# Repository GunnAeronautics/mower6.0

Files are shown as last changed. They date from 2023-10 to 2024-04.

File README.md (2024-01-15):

# mower6.0
How to install build onto rasberry pi pico:

Get Vscode

Get Git

Install the extension platformio

Download the repository

Enable LongPaths:

For windows:

Open Registry Editor,

go to:

HKEY_LOCAL_MACHINE\SYSTEM\CurrentControlSet\Control\FileSystem.

Select the entry named: LongPathsEnabled. Set the value to 1

Run Git CMD as administrator

Run this command:

git config --system core.longpaths true

Restart your computer

Open repo in platformio and it should start to build.

Download zadig driver installation tool if you want to upload more easily

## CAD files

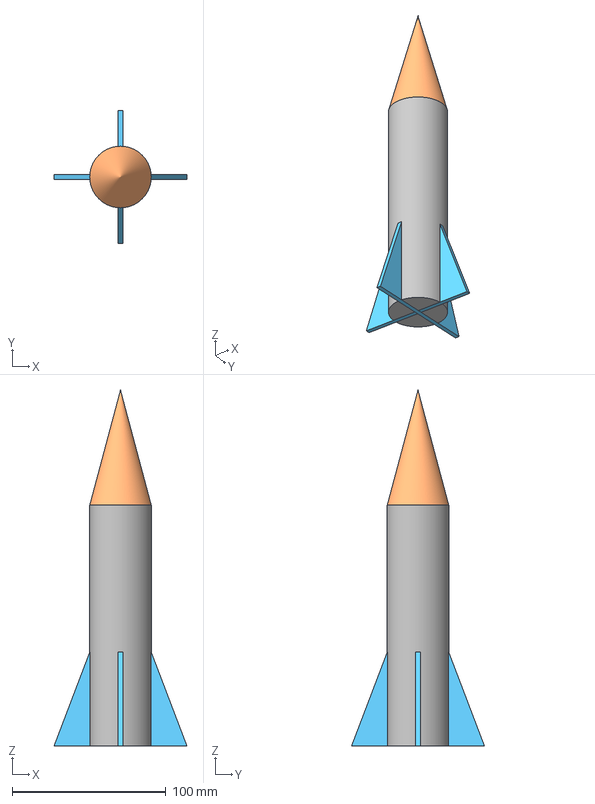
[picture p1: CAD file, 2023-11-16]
Flight Data Shenanigans/Python Testing/Rocket.3mf
86.5 x 86.5 x 231.4 mm

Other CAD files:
Flight Data Shenanigans/Python Testing/Rocket.obj

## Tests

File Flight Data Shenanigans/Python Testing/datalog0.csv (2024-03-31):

time | baro | temp | alt | altV | altA | predictApogee | srvPos | correl | state
321906 | 1007.88 | 28.06 | 0.47 | 0 | 0 | 0 | 0 | 0 | 1
321932 | 1007.9 | 28.06 | 0.48 | 0 | 0 | 0 | 0 | 0 | 1
321958 | 1007.86 | 28.05 | 0.53 | 0 | 0 | 0 | 0 | 0 | 1
321985 | 1007.89 | 28.06 | 0.51 | 0 | 0 | 0 | 0 | 0 | 1
322011 | 1007.86 | 28.06 | 0.54 | 0 | 0 | 0 | 0 | 0 | 1
322037 | 1007.89 | 28.06 | 0.51 | 0 | 0 | 0 | 0 | 0 | 1
322063 | 1007.87 | 28.06 | 0.51 | 0 | 0 | 0 | 0 | 0 | 1
322090 | 1007.87 | 28.06 | 0.47 | 0 | 0 | 0 | 0 | 0 | 1
322116 | 1007.86 | 28.06 | 0.44 | 0 | 0 | 0 | 0 | 0 | 1
322148 | 1007.87 | 28.06 | 0.42 | 0 | 0 | 0 | 0 | 0 | 1
322174 | 1007.87 | 28.05 | 0.41 | 0 | 0 | 0 | 0 | 0 | 1
322200 | 1007.89 | 28.06 | 0.36 | 0 | 0 | 0 | 0 | 0 | 1
322227 | 1007.88 | 28.06 | 0.42 | 0 | 0 | 0 | 0 | 0 | 1
322253 | 1007.9 | 28.06 | 0.42 | 0 | 0 | 0 | 0 | 0 | 1
322279 | 1007.89 | 28.06 | 0.46 | 0 | 0 | 0 | 0 | 0 | 1
322305 | 1007.88 | 28.06 | 0.42 | 0 | 0 | 0 | 0 | 0 | 1
322331 | 1007.88 | 28.06 | 0.41 | 0 | 0 | 0 | 0 | 0 | 1
322357 | 1007.9 | 28.06 | 0.4 | 0 | 0 | 0 | 0 | 0 | 1
322384 | 1007.84 | 28.06 | 0.44 | 0 | 0 | 0 | 0 | 0 | 1
322415 | 1007.89 | 28.07 | 0.42 | 0 | 0 | 0 | 0 | 0 | 1
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

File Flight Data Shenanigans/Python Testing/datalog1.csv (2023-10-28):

time | x accl | y accl | z accl | gyro x | gyro y | gyro z | pressure
6518 | 0.07 | -0.05 | 9.99 | -0.00 | 0.00 | 0.00 | 1021.80
6606 | 0.07 | -0.10 | 9.95 | -0.00 | 0.00 | 0.00 | 1021.79
6693 | 0.08 | -0.06 | 9.96 | -0.00 | 0.00 | 0.00 | 1021.79
6780 | 0.11 | -0.05 | 9.98 | -0.00 | 0.01 | 0.00 | 1021.80
6867 | 0.04 | -0.11 | 9.98 | -0.00 | 0.00 | 0.00 | 1021.78
6954 | 0.07 | -0.02 | 9.99 | -0.00 | 0.00 | 0.00 | 1021.81
7041 | 0.08 | -0.07 | 9.97 | -0.00 | 0.00 | 0.00 | 1021.80
7128 | 0.09 | -0.08 | 9.99 | -0.00 | 0.00 | 0.00 | 1021.79
7216 | 0.05 | -0.04 | 9.99 | -0.00 | 0.00 | 0.00 | 1021.78
7303 | 0.10 | -0.07 | 9.97 | -0.00 | 0.00 | 0.01 | 1021.75
7395 | 0.06 | -0.07 | 9.98 | -0.00 | 0.00 | 0.00 | 1021.81
7482 | 0.09 | -0.05 | 9.99 | -0.00 | 0.00 | 0.00 | 1021.79
7569 | 0.07 | -0.08 | 9.98 | -0.00 | 0.00 | 0.00 | 1021.76
7657 | 0.07 | -0.04 | 10.00 | -0.00 | 0.00 | 0.00 | 1021.77
7744 | -1.97 | 1.45 | 10.02 | -0.01 | 0.00 | -0.17 | 1021.76
7831 | -1.47 | 1.31 | 9.88 | -0.03 | 0.03 | -0.19 | 1021.74
7918 | 3.16 | -0.71 | 10.00 | -0.01 | 0.01 | 1.44 | 1021.77
8006 | -0.42 | 0.43 | 9.95 | 0.00 | 0.00 | -0.10 | 1021.75
8093 | -0.05 | -0.02 | 10.02 | 0.01 | 0.00 | 0.06 | 1021.75
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

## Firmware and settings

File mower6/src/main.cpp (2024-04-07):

#include <Arduino.h>
#include <SPI.h>
#include <SD.h>
#include <Bounce2.h>
#include <Wire.h>
#include <Servo.h>
#include <Adafruit_LPS2X.h>
#include <Adafruit_Sensor.h>
#include <Adafruit_MPU6050.h>
#include <numeric>
#include <math.h>
#include <Adafruit_BMP3XX.h>
using namespace std;
#define ISBMP false
#define TARGET_HEIGHT 250//in meters
int state=0; //**DO NOT HAVE STATE AS -1 FOR ACTUAL LAUNCH** actual launch state is 0
float srvOffset = 0;


#define GRAVITY 9.807//m/s^2
#define ALT_THRESH 25
#define ROLLING_AVG_LEN 7

#define IMU_DATA_RATE MPU6050_CYCLE_40_HZ
#define BAROMETER_DATA_RATE LPS22_RATE_75_HZ

#define DEBUG_LED 25//Pin defs 
#define SD_CS 5
#define BARO_CS 6
#define SPI_SCLK 18
#define SPI_TX 19 
#define SPI_RX 20 
#define SERVO_ONE 13
#define SERVO_TWO 12
#define SERVO_THREE 11


unsigned long initialSweepMillis = 0;
//equation of line variables for linear regression
volatile double m;
volatile double b;
double correl;
bool ifsetup = true;
float LUT[21] = {//20x 0.05 radian increments starting from fully retracted final is 0.983
1.087//degree in radians of servo for fully retracted flaps
,1.073
,0.966
,0.912
,0.858
,0.805
,0.751
,0.697
,0.644
,0.590
,0.537
,0.483
,0.429
,0.376
,0.322
,0.268
,0.215
,0.161
,0.107
,0.054
,0.0};
  //Objects
File dataFile;
Bounce sw1,sw2;//Debouncing for switches
Adafruit_LPS22 baro;
Adafruit_MPU6050 mpu;
Adafruit_BMP3XX bmp; //adafruit you're terrible
Servo srv;
double groundTemperature;
double groundPressure;
double altVTemp;
int globalIndex = 0;//current index being written by rolling avg class-written in loop
double baroRaw[ROLLING_AVG_LEN];
double baroTemperRaw[ROLLING_AVG_LEN];
double IMUAccelRaw[ROLLING_AVG_LEN];
double pressureVelocity[ROLLING_AVG_LEN];
double baroAlt[ROLLING_AVG_LEN];
double kVals[ROLLING_AVG_LEN];
double input_times[ROLLING_AVG_LEN];
double flapAngles[ROLLING_AVG_LEN];
float currentFlapAngle;
float srvPos;
void shiftArray(double newData, double *array, int index) {
  array[index] = newData; // replace index value with the new data
  return;
}
double getRollingAvg(double array[]){
  double sum = 0;
  return ((std::accumulate(array,array+ROLLING_AVG_LEN,sum))/ROLLING_AVG_LEN);
}
void setInputTime(){
  shiftArray((double)millis()/1000,input_times,globalIndex);
}
void inputNewData(double newdata, char datatype){//b = pressure, t=temp, a=imuaccl, v=baroVelocity, A= altitude, k=K, f=flap angle
  switch (datatype) { 
    case 'b':shiftArray(newdata, baroRaw, globalIndex);break;
    case 't':shiftArray(newdata, baroTemperRaw, globalIndex);break;
    case 'a':shiftArray(newdata, IMUAccelRaw, globalIndex);break;
    case 'v':shiftArray(newdata, pressureVelocity, globalIndex);break;
    case 'A':shiftArray(newdata, baroAlt, globalIndex);break;
    case 'k':shiftArray(newdata, kVals, globalIndex);break;
    case 'f':shiftArray(newdata, kVals, globalIndex);break;
  }
    }
double recieveRolledData(char datatype){//b = pressure, t=temp, a=imuaccl, v=baroVelocity, A= altitude
  switch (datatype) {
    case 'b':return getRollingAvg(baroRaw);break;
    case 't':return getRollingAvg(baroTemperRaw);break;
    case 'a':return getRollingAvg(IMUAccelRaw);break;
    case 'v':return getRollingAvg(pressureVelocity);break;
    case 'A':return getRollingAvg(baroAlt);break;
    case 'k':return getRollingAvg(kVals);break;
    case 'f':return getRollingAvg(flapAngles);break;
  }
  return 0;
}
double recieveRawData(char datatype) { //b = pressure, t=temp, a=imuaccl, v=baroVelocity, A= altitude
  switch (datatype) {
  case 'b':return baroRaw[globalIndex];break;
  case 't':return baroTemperRaw[globalIndex];break;
  case 'a':return IMUAccelRaw[globalIndex];break;
  case 'v':return pressureVelocity[globalIndex];break;
  case 'A':return baroAlt[globalIndex];break;
  case 'k':return kVals[globalIndex];break;
  case 'f':return flapAngles[globalIndex];break;
}
return 0;
}


String fname="datalog.csv";

unsigned long lastT;
volatile double deltaT;


double altitudeA;

#define SIMULATION false
#if SIMULATION
  double realAlt = 40;
  double realVel = 120;
  double realAccel = 2;//still 0 in perfect free fall and negative if going down
  double flapDragCoef = 0.003;
  double rocketDrag = 0.003;
#endif
float radiansToDegrees(float angle){
  return angle*180/PI;
}
float DegreesToRadians(float angle){
  return angle/180*PI;
}
float flapAngleToServoAngle(float flapAngle){
  flapAngle = DegreesToRadians(flapAngle);
  if (flapAngle > 0.983){
    flapAngle = 1;
  }
  else if (flapAngle < 0){
    flapAngle = 0.05;
  }
  return radiansToDegrees(LUT[int(round(flapAngle*20))]);
  }
double pressToAlt(double pres){ //returns alt (m) from pressure in hecta pascals and temperature in celsius - FULLY TESTED
  return (double)(((273.0+groundTemperature)/(-.0065))*((pow((pres/groundPressure),((8.314*.0065)/(GRAVITY*.02896))))-1.0)); //https://www.mide.com/air-pressure-at-altitude-calculator, https://en.wikipedia.org/wiki/Barometric_formula 
}
int linreg(volatile double x[], volatile double y[], volatile double *m, volatile double *b, double *r) { // stolen code
  float sumx = 0;                           // sum of x
  float sumx2 = 0;                          // sum of x**2
  float sumxy = 0;                          // sum of x * y
  float sumy = 0;                           // sum of y
  float sumy2 = 0;                          // sum of y**2
  for (int i = 0; i < ROLLING_AVG_LEN; i++) {
    sumx += x[i];
    sumx2 += pow(x[i],2);
    sumxy += x[i] * y[i];
    sumy += y[i];
    sumy2 += pow(y[i],2);
  }

  float denom = (ROLLING_AVG_LEN * sumx2 - pow(sumx,2));
  if (denom == 0) { // vertical line
    // singular matrix. can't solve the problem.
    // *m = 0;
    // *b = 0;
    if (r)
      *r = 0;
    return 1;
  }

  *m = (ROLLING_AVG_LEN * sumxy - sumx * sumy) / denom;
  *b = (sumy * sumx2 - sumx * sumxy) / denom;
  if (r != NULL) {
    *r = (sumxy - sumx * sumy / ROLLING_AVG_LEN) / // compute correlation coeff
         sqrt((sumx2 - sqrt(sumx) / ROLLING_AVG_LEN) *
              (sumy2 - sqrt(sumy) / ROLLING_AVG_LEN));
  }
  return 0;
}
double dummyB,dummyCorrel;//dump locations for lin reg on velocity & acceleration
void dataStuff(){
  
  sensors_event_t temper;
  sensors_event_t pressure;
  sensors_event_t a, g, temperate;
  
	mpu.getEvent(&a, &g, &temperate);
  baro.getEvent(&pressure, &temper);
  inputNewData(pressure.pressure,'b');
  inputNewData(temper.temperature,'t');

   inputNewData((-1*a.acceleration.y),'a');//add magnitude of acceleration - no gravity adjustment
   setInputTime();

  if (!ifsetup){
    inputNewData(pressToAlt( recieveRawData('b')),'A');
  }
  else{
    inputNewData(0,'A');
  }
  linreg( input_times, baroAlt,&altVTemp,&dummyB, &dummyCorrel);
  inputNewData(altVTemp,'v');
  linreg( input_times, pressureVelocity,&altitudeA,&dummyB, &dummyCorrel);
  
  
  //inputting k via a/v^2
   inputNewData( abs(recieveRawData('a'))/(pow( recieveRawData('v'),2)),'k');
}
#if SIMULATION
void simulatedDataStuff(){
  if (!ifsetup){
  realAlt += realVel * deltaT;
  if ((realAlt < 0) || (realAlt == 0)){
    realAlt = 0;
  }
  realVel += ((realAccel-GRAVITY) * deltaT);
  if (realAlt == 0){
    realVel = 0;
  }
  realAccel = (0-realVel)*abs(realVel*0.7)* (sin(DegreesToRadians(currentFlapAngle)*flapDragCoef)+rocketDrag);//negative means going down
    if (realAlt == 0){
    realAccel = 0;//normal force lmao
  }
  };
  inputNewData(realAlt,'A');//displacment
  setInputTime();
  linreg( input_times, baroAlt,&altVTemp,&dummyB, &dummyCorrel);
  if (!ifsetup){
  inputNewData(altVTemp,'v');
  }
  else{
    inputNewData(realVel,'v');
  }
  inputNewData(0-realAccel,'a');
  inputNewData( recieveRawData('a')/(pow( recieveRawData('v'),2)),'k');
  
}
#endif
double predictApogee (double k,double v,double alt){ // finds the distance to max alt, takes v and k - ONLY VALID FOR COASTING, assumes raw imu acceleration values
return alt + log((k*v*v/GRAVITY)+1)/(2.0*k);
}
float inverseApogee(double desiredApogee, double v) { // Working & Tested
  float searchRangeH = 20;
  float searchRangeL = 0;//SEARCH RANGE IS 0<m<20
  float mid;
  for (int i = 0; i < 20; i++) {
    mid = (searchRangeL + searchRangeH) / 2.0;
    float prediction = predictApogee(mid, v, mid*v*v);

    if (prediction < desiredApogee) { // to the left of desired
      searchRangeH = mid;
    } else if (prediction > desiredApogee) {
      searchRangeL = mid;
    }
  }
  return mid;
}

#define ONLYFUNKY true
#define FUNKYLOGISTIC true //if this is false then the program will use a simple method rather than a curve if the correlation is low betweek k and flap angle
double finalcalculation (){ 
  float currK= recieveRolledData('k'); float currV= recieveRolledData('v');
  float altPrediction = predictApogee(currK,currV, recieveRolledData('A'));
  float altError=altPrediction-TARGET_HEIGHT;//the amount of added error to get perfect target height
  //error is + if going over and - if going under
  #if ONLYFUNKY
    double result;
  if(altError>0){result= currentFlapAngle+(3.0/(1.0+exp(.2*(-abs(altError)+20.0))));}
   else{result= currentFlapAngle-(3.0/(1.0+exp(.2*(-abs(altError)+20.0))));}
   if (result>90){
    return 90;
   }
    /*
    if (altError > 0){//going under
      //return currentFlapAngle-1;
      result= currentFlapAngle+2;
    }
    else{
      //return currentFlapAngle+1;
      result= currentFlapAngle-2;
    }//*/


   else if(result<0){
    return 0;
   } else{
    return result;
   }
  //  return 90.0/(1+exp(.2*(-abs(altError)+20)));
  #else

  if(altError<(-TARGET_HEIGHT*.01)){ //just reduce the flap angle if under shooting
    return flapAngles[globalIndex]-1;
  } 

  if(!linreg(kVals,flapAngles,&m,&b,&correl)){
    Serial.println("linear regression failed, just increasing flap");
    return flapAngles[globalIndex]+1;
  } //find flapAngle/k
    float desiredK=inverseApogee(TARGET_HEIGHT,recieveRawData('v'));
  if(pow(correl,2)<.4||isinf(m*desiredK+b)){ //if correlation is low (and overshooting) just use a logistic function to adjust flap angle- https://www.desmos.com/calculator/emvbfgtl5t - might cause some oscillations
    #if FUNKYLOGISTIC==true
    if(altError>0){return flapAngles[globalIndex]+10.0/(1+exp(.2*(-abs(altError)+20)));}
    else{return flapAngles[globalIndex]-10.0/(1+exp(.2*(-abs(altError)+20)));}
    return 90.0/(1+exp(.2*(-abs(altError)+20)));
    #else //switching between logistic method and a basic addition method
    return flapAngles[globalIndex]+1*(altError>0)-1*(altError<=0); 
    #endif
  }
    
  //find k needed

  return m*desiredK+b; //use regression line to find flap angle that should theoretically give us optimal values
  #endif
}

void writeSDData(){ 
  String dataString = (String)millis() + ',' +
                      (String) (recieveRolledData('A'))+ ',' + //alt
                      (String) (recieveRolledData('v')) + ',' + //velocity - baro derived
                      (String) (recieveRolledData('a')) + ',' +//accel - imu derived
                      //(String)(altitudeA*1000) + ',' +//accl baro
                      (String)predictApogee( recieveRolledData('k'), recieveRolledData('v'),recieveRolledData('A')) + ',' + //apogee prediction
                      (String)srvPos + ',' +
                      (String)currentFlapAngle + ',' + //flap angle
                      (String)state+','+(String)correl + ','+(String)deltaT;
                      
  File dataFile = SD.open(fname, FILE_WRITE);
    // if the file is available, write to it:
  if (dataFile) {
      dataFile.println(dataString);
      dataFile.close();
  }
  else {
    Serial.print("error opening ");
    Serial.println(fname);
  }
}



void setup() {

  Serial.begin(115200);
  delay(7000);
  Serial.println("haiiiiii >_< :3");
  pinMode(LED_BUILTIN,OUTPUT);
      digitalWrite(LED_BUILTIN,HIGH);
      delay(200);
      digitalWrite(LED_BUILTIN,LOW);
  // Ensure the SPI pinout the SD card is connected to is configured properly

  SPI.setRX(SPI_RX);
  SPI.setTX(SPI_TX);
  SPI.setSCK(SPI_SCLK);
  #if !ISBMP //switches between lps22 and BMP388 DONT MISS THIS ONE TONY PLS :)
  Serial.print("Barometer initialized, initialization bool = ");Serial.println(baro.begin_SPI(BARO_CS));
  baro.setDataRate(BAROMETER_DATA_RATE);
  #endif

  Serial.print("Initializing SD card...");
    if (!SD.begin(SD_CS)) {
    Serial.println("Card failed, or not present");

      while(true){
        digitalWrite(DEBUG_LED,1);
        delay(200);
        digitalWrite(DEBUG_LED,0);
        delay(200);
      }
    }
    else {

      Serial.println("SD initialized");
        delay(100);
        fname="datalog"+(String)0+".csv";

        for (int i=0; i<999&&(SD.exists(fname));i++){ //add detection if file already exists
          fname="datalog"+(String)i+".csv";
          Serial.print("tried ");
          Serial.println(fname);
        }
        File dataFile = SD.open(fname, FILE_WRITE);
        
        if (!dataFile){
          Serial.println("dat file not initialized, name = ");
          Serial.print(fname);
          while(true){
            digitalWrite(LED_BUILTIN,1);
            delay(500);
            digitalWrite(LED_BUILTIN,0);
            delay(500);
          }
        } else {
          Serial.println("dat file successfully initialized, name = ");
          Serial.print(fname);
          dataFile.println("time,altitude,baro velocity,imu acceleration,apogee predicted,servo pos,flap angle,state");
        dataFile.close();
        }
    }
    Wire.setSCL(9);
    Wire.setSDA(8);
    
  if (!mpu.begin(0x68,&Wire)) {
		Serial.println("Failed to find MPU6050 chip");
		while (1) {
		  delay(10);
		}
	}
  mpu.setCycleRate(IMU_DATA_RATE);
  mpu.setAccelerometerRange(MPU6050_RANGE_16_G);
  Serial.println("MPU6050 chip found");
  mpu.setCycleRate(IMU_DATA_RATE);

  delay(1000);
  Serial.println("waiting for launch");

  for (int i=0; (i < ROLLING_AVG_LEN); i++){
    #if SIMULATION
      simulatedDataStuff();
    #else
      dataStuff();//zeros a bunch of stuff
    #endif
    delay(100);
    globalIndex++;
    globalIndex%=ROLLING_AVG_LEN;
  }
  
  groundTemperature =  recieveRolledData('t'); //used as ground reference
  groundPressure =  recieveRolledData('b'); 
  Serial.println("Zeroed Altitude");
  srv.attach(SERVO_ONE); //closest to board
  
  delay(1000);
  srv.write(3*(flapAngleToServoAngle(0)+ srvOffset));
  delay(3000);
  for (int i=0; i < 30; i++){
    srv.write(3*(flapAngleToServoAngle(i*2)+srvOffset));
    delay(25);
  }
  delay(3000);
  for (int i=30; i > 0; i--){
    srv.write(3*(flapAngleToServoAngle(i*2)+srvOffset));
    Serial.println(i);
    delay(25);
  }
  lastT = millis();
  ifsetup = false;  
  
}


uint8_t consecMeasurements = 0; //used for state transitions
int timer;
void loop() {
  deltaT = (millis() - lastT)/1000.0;//1000;// in seconds
  lastT = millis();// in seconds
  #if SIMULATION
    simulatedDataStuff();
  #else
    dataStuff();
  #endif

  switch (state){

   case -1: //debug
    writeSDData();
    if (timer < millis()){

    Serial.print("Baro:");
    Serial.print( recieveRawData('b'));
    Serial.print(" DeltaT:");
    Serial.print(deltaT*1000);
    Serial.print(" Yaccel:");
    Serial.print(altitudeA);
    Serial.print(" Yaccel2:");
    Serial.print( recieveRolledData('a'));
    Serial.print(" Yvel:");
    Serial.print( recieveRolledData('v'));
    Serial.print(" Yalt:");
    Serial.println(recieveRawData('A'));
    timer = millis() + 300;
    }
   break;

  case 0: //
    if (recieveRolledData('A')> 3){ 
        state = 1;//rocket has gone off the launch pad
      }

      currentFlapAngle = 0;

    writeSDData();
    break;
  case 1://during initial burn
    if (recieveRolledData('A')> ALT_THRESH&&recieveRolledData('a')>0){ //waiting for rocket deccelerating and above threshold
      state = 2;//rocket has stopped accelearting
    }
    currentFlapAngle = 0;
    writeSDData();
    break;
  case 2:
    if (consecMeasurements == 6){
        state = 3;
        consecMeasurements=0;
      }
    else if (recieveRolledData('v') <-2){
        consecMeasurements++;
      }
    else{
        consecMeasurements = 0;
      }
    currentFlapAngle=finalcalculation();
    writeSDData();
    break;


  case 3://falling
  if (consecMeasurements == 10){
        state = 4;
        consecMeasurements=0;
      }
    else if ((recieveRolledData('v') > -0.1) && (recieveRolledData('v') < 0.1)){//reliable
        consecMeasurements++;
      }
    else{
        consecMeasurements = 0;
      }
    currentFlapAngle=0;
    
    writeSDData();
    delay(150);
    break;

  case 4://on the ground, do nothing
    digitalWrite(DEBUG_LED,1);
    delay(200);
    digitalWrite(DEBUG_LED,0);
    delay(200);
    break;
  }

  srvPos = flapAngleToServoAngle(currentFlapAngle);
  srv.write(3*(srvPos+srvOffset));
  inputNewData(currentFlapAngle,'f');

  globalIndex++;
  globalIndex%=ROLLING_AVG_LEN;
  
}

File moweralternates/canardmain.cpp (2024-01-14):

#include <Arduino.h>
#include <SPI.h>
#include <SD.h>
#include <Bounce2.h>
#include <Servo.h>
//using adafruit's libraries
#include <Adafruit_LSM6DS.h>
#include <Adafruit_LPS2X.h>
#include <Adafruit_Sensor.h>
#include <numeric>

/*


the LPS22 is reffered to as baro here, not altimeter because shorter, LSM6DSMXX is reffered to as IMU

SPI frequency currently set by setclockdivider(16) to around 8 MHz

*/


//#define SPI_FREQ 10000000 
 // IMPORTANT: ADJUST BEFOER FLIGHT
#define TARGET_TIME 44.5 //in seconds
#define TARGET_HEIGHT 250//in meters





//debug mode adds serial messages and some extra stuff
//IMPORTANT: IF YOU WANT TO DISABLE, COMMENT OUT, DONT SET FALSE
#define ISDEBUG true
//#define ISCANARD true
#define ISDRAGFLAP true


/* template for debug message:

#ifdef ISDEBUG
Serial.println(" ");
#endif

*/
#define ACCEL_THRESH 18 
#define ALT_THRESH 25 //meters above initial
#define SRV_MAX_ANGLE 7 //in degrees
#define ROCKET_ANGLE_TOLERANCE 5 //in degrees

#define IMU_DATA_RATE LSM6DS_RATE_52_HZ
#define BAROMETER_DATA_RATE LPS22_RATE_25_HZ

//amount of rolling average numbers to keep track of
#define ROLLING_AVG_LEN 5

#define SRV_SWEEP_TIME 2500//in millis

//Pin defs
#define SRV1_PIN 4
#define SRV2_PIN 5
#define SRV3_PIN 6
#define SRV4_PIN 7
#define SRV5_PIN 8
#define IMU_INT1 11
#define IMU_INT2 10
#define BARO_INT 12
#define DEBUG_LED 13
#define IMU_CS 9
#define SD_CS 14
//TX = DO = MOSI, RX = DI=MISO
#define SPI_SCLK 18
#define SPI_TX 19 //AKA mosi
#define SPI_RX 20 //AKA miso
#define BARO_CS 15
#define CTRL_SW1 26
#define CTRL_SW2 22
#define BUZZ_PIN 27 //using tone function


    //Runtime variables
  int state=0;

  unsigned long lastBeepTime = 0; //the last time the beep happened during case 4 (beep)

  volatile float srvPos[5]; //servo position array
  float srvOffsets[5] = {0,0,0,0,0};

  volatile bool newSensorDat = false;


  float referenceGroundPressure;
  float referenceGroundTemperature;
  int8_t consecMeasurements = 0; //this variable should never be greater than 4. Defined as 8-bit integer to save memory



  unsigned long initialSweepMillis = 0;


  //stuff for adafruit's libraries
  sensors_event_t accel;
  sensors_event_t gyro;
  sensors_event_t pressure;
  sensors_event_t tempIMU;
  sensors_event_t tempBaro;

  //filtered data - keeping past 2 values to enable differentiation
float pitchAngleFiltered;//Not Used
float velocityX,velocityY,velocityZ;
float velocityZbaro[2];
float velocityZAccel[2];
float temperature;
volatile float rocketAngle[3];//integrated
volatile float desiredAngle;

  //Objects
File dataFile;
  //Debouncing for switches
Bounce sw1,sw2;

Adafruit_LSM6DS imu;
Adafruit_LPS22 baro;

Servo srv[5];

roll roller;
class roll{//tested
  public:
    float acclRaw[3][ROLLING_AVG_LEN]; //x,y,z
    float gyroRaw[3][ROLLING_AVG_LEN]; //x,y,z
    float baroRaw[ROLLING_AVG_LEN];
    float baroTempRaw[ROLLING_AVG_LEN];
   void clipVariables(float max,float ceiling,float min, float floor,int arrayToUse){ //case 1 = accl, 2= gyro, 3= altitude
    switch(arrayToUse){
      case(1): //accel data
      for (int j=0; j<3;j++){
        for (int i=0; i<ROLLING_AVG_LEN;i++){
          if (acclRaw[j][i]>=max){
            acclRaw[j][i]= ceiling;
          } else if (acclRaw[j][i]<=min){
            acclRaw[j][i]=floor;
          }
        }
      }
      
      break;

      case(2): //gyro data
      for (int j=0; j<3;j++){
        for (int i=0; i<ROLLING_AVG_LEN;i++){
          if (gyroRaw[j][i]>=max){
            gyroRaw[j][i]= ceiling;
          } else if (gyroRaw[j][i]<=min){
            gyroRaw[j][i]=floor;
          }
        }
      }
      break;

      case(3): //alt data

        for (int i=0; i<ROLLING_AVG_LEN;i++){
          if (baroRaw[i]>=max){
            baroRaw[i]= ceiling;
          } else if (baroRaw[i]<=min){
            baroRaw[i]=floor;
          }
        }
      
      break;
      
      default:
      break;

    }
   }

    void shiftArray(float newData, float *array){
      for (int i=0; i<ROLLING_AVG_LEN-1; i++){ //downshift all values
         array[i]=array[i+1];
      }
      array[ROLLING_AVG_LEN-1]=newData; //replace final value with the new data
      return;
    }

    float getAvgInRollingAvg(float array[]){
      float sum = 0;
      return ((std::accumulate(array,array+ROLLING_AVG_LEN,sum))/ROLLING_AVG_LEN);
    }

    void inputNewData(float newdata, char datatype){
      switch (datatype) { 
        case 'X': shiftArray(newdata,acclRaw[0]) ; break;
        case 'Y': shiftArray(newdata,acclRaw[1]) ; break;
        case 'Z': shiftArray(newdata,acclRaw[2]) ; break;
        case 'x': shiftArray(newdata,gyroRaw[0]) ; break;
        case 'y': shiftArray(newdata,gyroRaw[1]) ; break;
        case 'z': shiftArray(newdata,gyroRaw[2]) ; break;
        case 'b': shiftArray(newdata,baroRaw)    ; break;
        case 't': shiftArray(newdata,baroTempRaw); break;
      }
      
    }



    float recieveNewData(char datatype){
      switch (datatype) {
        case 'X': return getAvgInRollingAvg(acclRaw[0]) ; break;
        case 'Y': return getAvgInRollingAvg(acclRaw[1]) ; break;
        case 'Z': return getAvgInRollingAvg(acclRaw[2]) ; break;
        case 'x': return getAvgInRollingAvg(gyroRaw[0]) ; break;
        case 'y': return getAvgInRollingAvg(gyroRaw[1]) ; break;
        case 'z': return getAvgInRollingAvg(gyroRaw[2]) ; break;
        case 'b': return getAvgInRollingAvg(baroRaw) ; break;
        case 't': return getAvgInRollingAvg(baroTempRaw) ; break;
      }
      return 0;
    }

    float recieveRawData(char datatype){
      switch (datatype) {
        case 'X': return acclRaw[0][ROLLING_AVG_LEN-1] ; break;
        case 'Y': return acclRaw[1][ROLLING_AVG_LEN-1] ; break;
        case 'Z': return acclRaw[2][ROLLING_AVG_LEN-1] ; break;
        case 'x': return gyroRaw[0][ROLLING_AVG_LEN-1] ; break;
        case 'y': return gyroRaw[1][ROLLING_AVG_LEN-1] ; break;
        case 'z': return gyroRaw[2][ROLLING_AVG_LEN-1] ; break;
        case 'b': return baroRaw[ROLLING_AVG_LEN-1] ; break;
        case 't': return baroTempRaw[ROLLING_AVG_LEN-1] ; break;
      }
      return 0;
    }
};

String fname;

void setup() {
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

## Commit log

2023-10-13 elis nightly "im going to go to sleep at 1030 this time fr ong"
    I did some cool stuff - reordered a ton of stuff, still need to do a lot but its goin in the right direction. Need to implement a lot of stuff I didnt mention like the actual flight loop, different v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
2023-10-14 Some more shanenigans
    Almost done with setup - still need to find kalman filter library or implement it myself/ some other filter, implement more of a control loop, and in general flesh stuff out more/remove some cobwebs.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
2023-10-14 case 4 scuffed
2023-10-14 case 4 but less scuffed
2023-10-16 Fixed and improved roll class implementation
    added clip variables functionality, clarified variable names, made the shift array functionality actually work with poitners, deleted SD stuff for now until we finish everything else
    [main.cpp]
2023-10-16 fixed broken if statement
    [main.cpp]
2023-10-16 added delay between buzzes
    [main.cpp]
2023-10-17 first shell of case 3 implementation
2023-10-17 did some reformatting n fixed a buch of stuff up
    there are 5 servos now - one for the chute.
    changed pin numbers to mirror the new pcb
    [main.cpp]
2023-10-18 case 3 shelled out, predictLandTime() still TBD
2023-10-18 Case 3 complete with predictLandTime()
2023-10-21 Adjusted pinout for pcb
    :)
2023-10-22 switches working now
    got switches working, still workgn on getting imu and baro readouts with interrupts, maybe theyre happening once but not being reset?? or mb theyre inverted??
    [main.cpp]
2023-10-22 Case 0 Testing Data Output Removed Servo Testing
2023-10-28 flight data stuff upload
    [datalog1.csv]
2023-10-29 Integral & Derivative Functions + More Data
    [datalog0.csv, datalog2.csv]
2023-11-04 Made it better and worse
    now utilizing both cores, issues: imu is hogging the spi0
    [main.cpp]
2023-11-07 Got picoprobe working
    can now do actual debugging, using uart1 to communicate with picoprobe now
2023-11-09 Data Organization Rewrite
    Implemented SD Card data logging.
    fixed integration for angle and velocity.
    removed unnecessary variables
    TODO: Need to fix baro filtering. need to fix control loop base 1 shenanigans.
    [main.cpp]
2023-11-09 Small Fixes
    base 1 fix and other things
    [main.cpp]
2023-11-09 Imported model of rocket to data visualizer
    [Rocket.3mf, Rocket.obj]
2023-11-11 Added temperature to barometric equation also fixed unused altitude algorithm
    More accurate altitude + minor bug fixes
    [main.cpp]
2023-11-11 Reference Ground Measurements
    No more having to recalculate ground measurements :D
2023-11-15 Minor Bug Fixes for delta
    [main.cpp]
2023-11-15 Fixed newDat booleans + minor bugfix for datalogging
    [main.cpp]
2023-11-17 BUNCH OF BUG FIXES + COMPAT FIX also all libraries should be included now
    [main.cpp]
2023-11-18 Mower6 Data Input moved to loop1, exit function out of case 2, SD data enabled
2023-11-19 Mower6 control loop
    changed control loop to the equation instead of waypoints. Made multi core variables volatile. created SD card comparison testing
    [Rocket.3mf, Rocket.obj, datalog0.csv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]
2023-11-19 tested sd card methods
    fixed it up n stuff
    [main.cpp]
2023-11-20 PID testing + QOL changes to mower 6.0
2023-11-21 mower6 PID implementation (unused) + PID testing upgrade for thrust curves
    [thrust.csv]
2023-11-23 Bug fixes + PID terminology update
    [main.cpp]
2023-12-03 Bug fixes, Canard control PID implementation, removed unneccessary variables. Good day :D
    [main.cpp]
2023-12-12 if anybody ever touches my code again theyre gone
    in the ground (removed conflicts n stuff)
2023-12-15 acceleration data filter
    may not work
    [main.cpp]
2024-01-14 Fixed a lot of functions, stringed together drag flap codebase. Also made rolling functions more optimize. Rolling class and Apogee functions are tested. Linear regression is not tested yet
    [canardmain.cpp, main.cpp]
2024-01-14 Formatted all the tabs, fixed some issues related with flaps. Basically just a bunch of house cleaning
    [main.cpp]
2024-01-19 Fixed some functions and cleaned up
    still a couple iffy sections that can get ironed out still but might need testing with actual rocket data like how well z acceleration adjustment works, whether we actually need the accelerometer at all, etc
    [main.cpp]
2024-01-21 Pin remap for mowerlite also removing imu mowerlite because broken
    [main.cpp]
2024-01-27 cut bloat + launch finalization, servo lines commented out
2024-03-31 MPU6050 implementation + LUT for srv angle as a function of flap angle + more house keeping + major bug fixes
    Horray Yippee, It's 1 AM I need some sleep
    [datalog0.csv]
2024-04-04 implemented basic control algorithm
    no oscillation control, switching between logistic and basic for if the regression doesn't look good
    [main.cpp]
2024-04-04 a couple more housekeepign things
    sweep sweep
2024-04-04 implemented bmp
    it prob doesnt work make sure to set the #define correctly or i will smite you
    [main.cpp]
2024-04-05 a couple more changes
    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
2024-04-06 fixes lin reg tested, LUT tested, sensors tested
    [main.cpp]
